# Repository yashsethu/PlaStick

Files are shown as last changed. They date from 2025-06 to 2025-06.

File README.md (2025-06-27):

# PlaStick
An affordable, customizable, and functional HOTAS flight controller!



CAD (here)[https://cad.onshape.com/documents/f1ad626c83caf2a9154e1274/w/2f9358a07325e282af4b0bc9/e/6182394e759cc8585870c80a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]

## Wiring Diagram



These wires are soldered, not part of any PCB

## Bill of Materials
| Quantity | Item | Link |
|---|---|---|
| 2 | Trigger spring 12mm long, 5mm OD, 4mm ID | Find in a ballpoint pen! |
| 2 | 5mmx10mm cylindrical magnet | [Amazon](https://www.amazon.com/Niuknow-Neodymium-10x5x2mm-Double-Sided-Adhesive/dp/B0BTSWZSVG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) |
| 4 | 6802zz Bearings | [Amazon](https://www.amazon.com/INFINAUTO-Bearings-15x24x5mm-Lubricated-Stylish/dp/B0DYNVTPV3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) |
| 4 | 685zz Bearings | [Amazon](https://www.amazon.com/uxcell-Bearing-Double-Shielded-Bearings/dp/B07FW26QBV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) |
| 8 | MF105zz Bearings | [Amazon](https://www.amazon.com/METERXITY-Shielded-Bearings-Wheelbarrow-Machines/dp/B0F4QWG4YM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) |
| 2 | M5x2mm | N/A |
| 2 | M5x30mm | N/A |
| 4 | M5x35mm | N/A |
| 8 | M2x12mm | N/A |
| 4 | M3x10mm | N/A |
| 2 | M3x22mm | N/A |
| 25 | 4.3x6x6 mm tactile switches | [Amazon](https://www.amazon.com/DAOKI-6x6x4-3mm-664-3mm-Momentary-Tactile/dp/B07X8S99RH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) |
| 1 | Arduino Pro Micro | [Amazon](https://www.sparkfun.com/pro-micro-5v-16mhz.html) |
| 3 (these break easily, buy extra) | Hall effect sensor | [Amazon](https://www.amazon.com/AH3503-UGN3503UA-UGN3503-Hall-Effect-Sensors/dp/B09N9SQK79) |

**For the bolts and hardware above, I have ommited links- find them at a hardware store or order a kit off Amazon! Buying them individually is pointless.**
**As for the Arduino Pro Micro, I am buying one direct from Sparkfun to avoid being ripped off with a non-genuine part. It costs 5-10 dollars more, but the complaints online about fake Pro Micros scare me enough into playing it safe** 

**Total Price: 85.99 (this could be a little bit higher or lower depending on Prime/where you live)**

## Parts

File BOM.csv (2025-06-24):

Quantity | Item
2 | M5x25
2 | M5x30
4 | M5x35
4 | 6802zz
8 | MF105zz
4 | 685zz
2 | 5mmx10mm cylindrical magnet
4 | 5-10 mm M3 bolts
2 | 20-22 mm M3 bolts
8 | M2 x 10-12mm
2 | M2 x 10-12mm
1 | Trigger spring 12mm long | 5mm OD | 4mm ID
22-25 | 4.3x6x6 mm tact switches

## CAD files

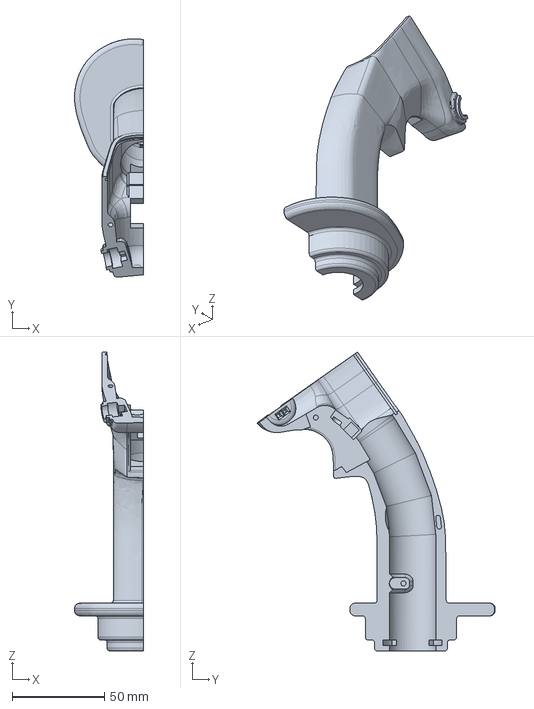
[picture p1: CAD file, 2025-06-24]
CAD/Full Assembly - Part 4.step
37.4 x 129.1 x 162.0 mm

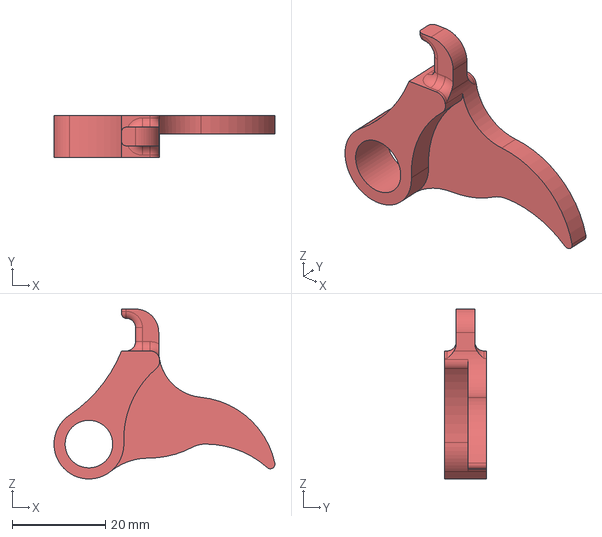
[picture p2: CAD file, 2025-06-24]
CAD/Full Assembly - Part 1 (12).step
47.5 x 9.00 x 36.5 mm

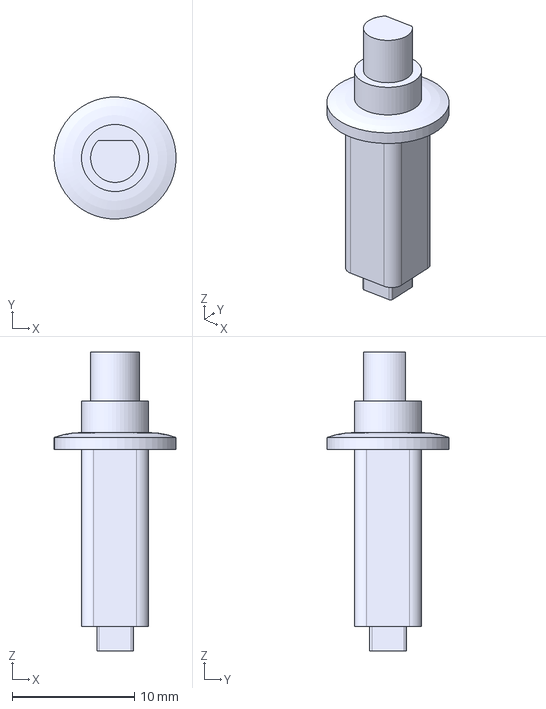
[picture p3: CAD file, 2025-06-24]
CAD/Full Assembly - Part 1 (17).step
9.99 x 10.00 x 24.5 mm

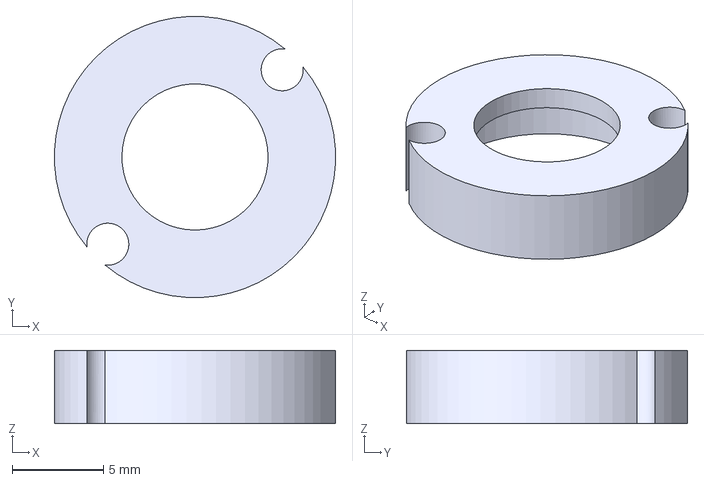
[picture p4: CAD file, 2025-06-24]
CAD/Full Assembly - Part 1 (29).step
15.4 x 15.4 x 4.00 mm

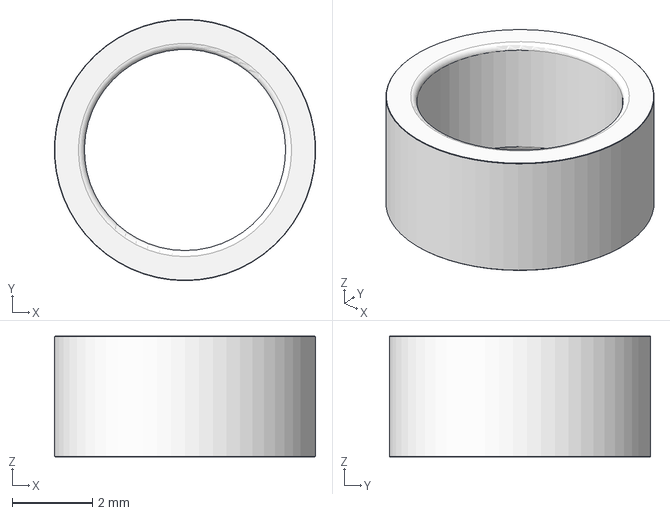
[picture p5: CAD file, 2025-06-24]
CAD/Full Assembly - p BEARING, METRIC 600 MINIATURE SERIES, DOUBLE-SHIELDED 5mm ID × 11 OD × 3 W — 685-ZZ (10).step
6.49 x 6.50 x 3.00 mm

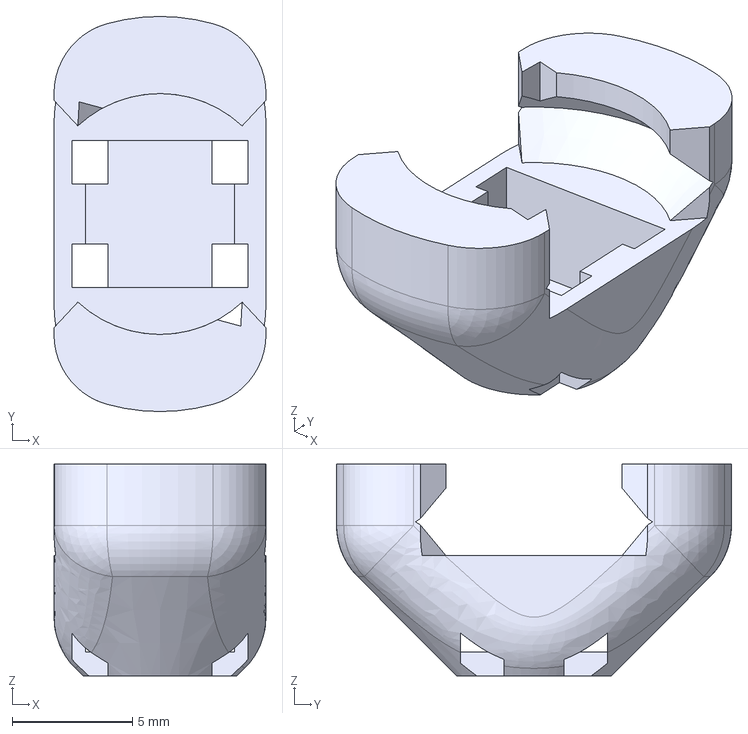
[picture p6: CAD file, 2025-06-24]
CAD/Full Assembly - Part 1 (13).step
8.80 x 16.4 x 8.80 mm

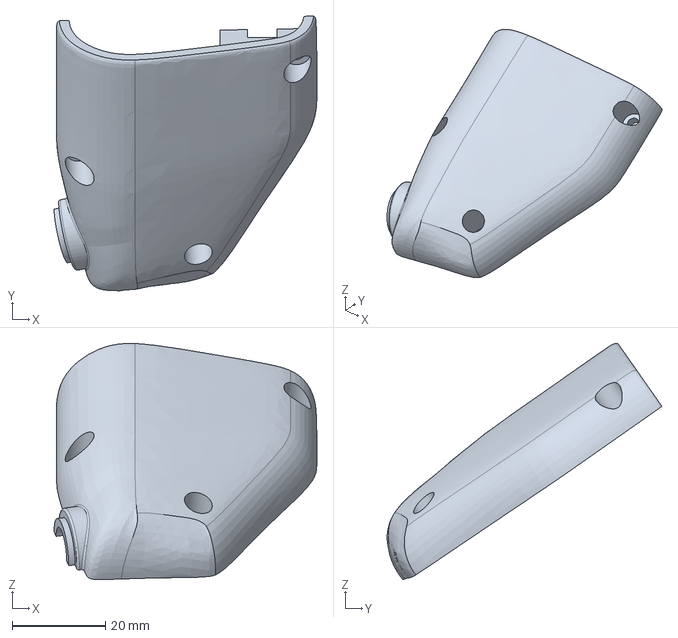
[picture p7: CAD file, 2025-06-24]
CAD/Full Assembly - Part 2.step
56.4 x 58.9 x 50.6 mm

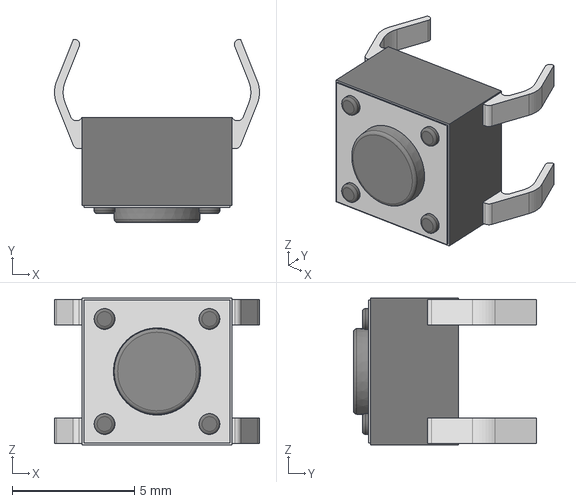
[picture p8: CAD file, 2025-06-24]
CAD/Full Assembly - Part 1 (37).step
8.37 x 7.48 x 5.99 mm

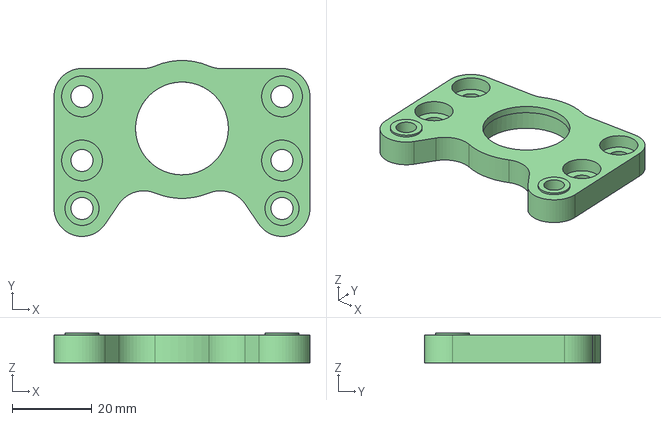
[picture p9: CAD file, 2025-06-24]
CAD/Full Assembly - gimbal_core_bearing_carrier_6802zz.step
64.0 x 44.0 x 7.50 mm

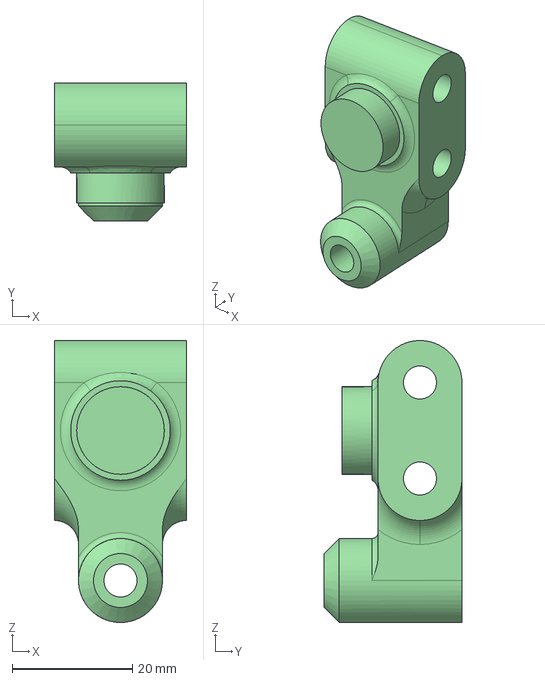
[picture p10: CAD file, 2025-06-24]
CAD/Full Assembly - Part 1 (45).step
22.0 x 23.0 x 47.0 mm

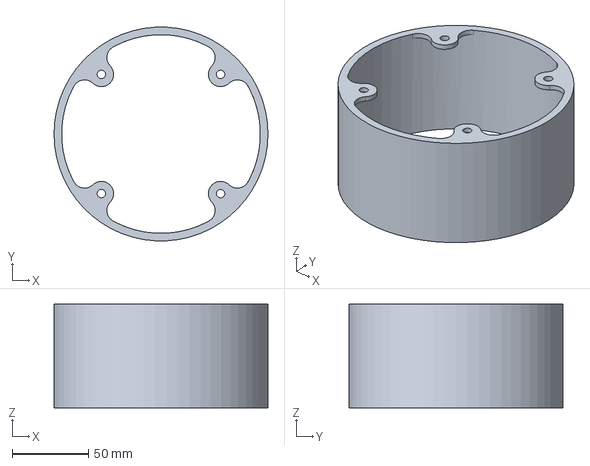
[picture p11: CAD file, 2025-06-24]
CAD/Full Assembly - Part 1 (11).step
140.0 x 139.8 x 68.0 mm

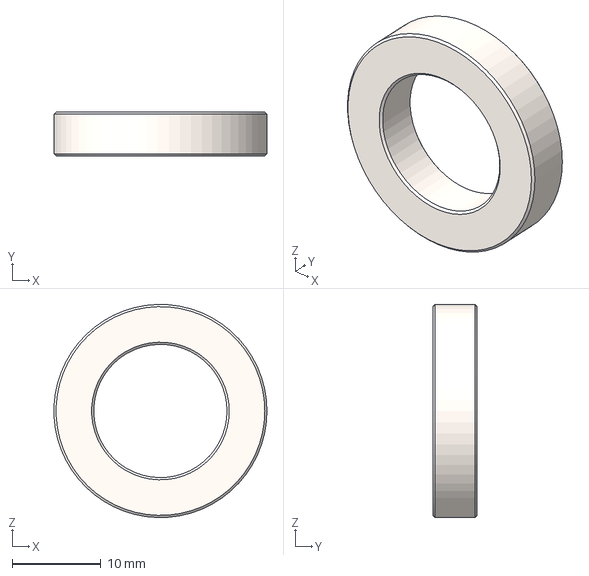
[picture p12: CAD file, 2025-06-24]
CAD/Full Assembly - Part 1 (38).step
24.0 x 5.00 x 24.0 mm

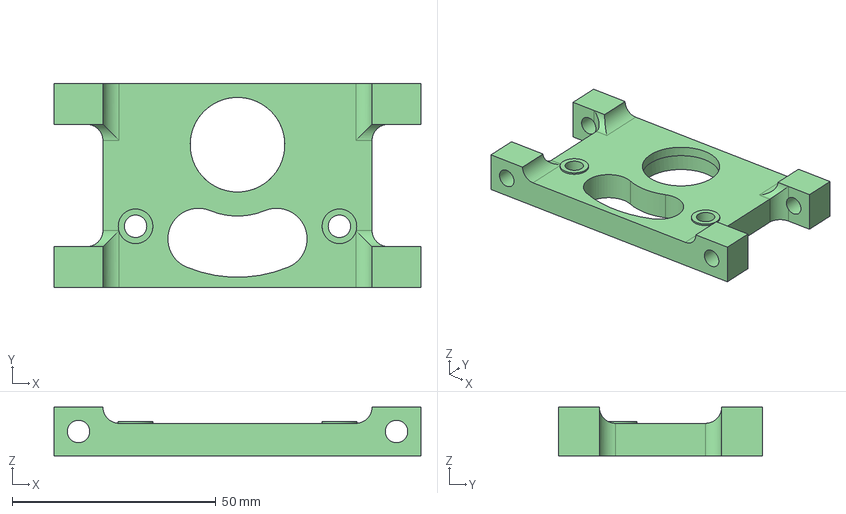
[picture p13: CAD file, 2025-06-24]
CAD/Full Assembly - gimbal_frame_6802zz.step
90.0 x 50.0 x 12.0 mm

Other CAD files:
CAD/Full Assembly - Part 1 (14).step
CAD/Full Assembly - Part 1 (21).step
CAD/Full Assembly - Part 1 (41).step
CAD/Full Assembly - Part 1 (35).step
CAD/Full Assembly - Part 1 (33).step
CAD/Full Assembly - Hex nut grade A & B M5x0.8 (1).step
CAD/Full Assembly - Hex nut grade A & B M5x0.8 (2).step
CAD/Full Assembly - Hex nut grade A & B M5x0.8 (3).step
CAD/Full Assembly - Hex nut grade A & B M5x0.8.step
CAD/Full Assembly - Hex socket countersunk head screw M5x0.8 x 20 (1).step
CAD/Full Assembly - Hex socket countersunk head screw M5x0.8 x 20.step
CAD/Full Assembly - Hex thin nut grade A & B M3 (1).step
CAD/Full Assembly - Hex thin nut grade A & B M3 (2).step
CAD/Full Assembly - Hex thin nut grade A & B M3 (3).step
CAD/Full Assembly - Hex thin nut grade A & B M3.step
CAD/Full Assembly - Hex thin nut grade A & B M5 (1).step
CAD/Full Assembly - Hex thin nut grade A & B M5 (2).step
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

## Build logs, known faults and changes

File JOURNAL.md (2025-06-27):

# Design Journal - Total time: 25 hrs

---
title: "PlaStick"
author: "Yash Sethuraman"
description: "An affordable, customizable HOTAS controller!"
created_at: "2025-06-24"
---

So, I really want a HOTAS flight stick, something like this:



But commercial HOTAS kits and stuff already online is either too expensive or too complicated for me. I want something minimal (at least mechanically) and functional.

# Part 1: The gimbal (3 hrs) 6/20/25

Before going crazy on the actual stick, I thought it would be nice to get the gimal out of the way. The first choice for most DIYers out there (according to Reddit) is a gimbal designed by (Oluleko)[https://www.thingiverse.com/thing:2496028/comments].

I really liked how compact and simple the gimbal was, but looking at the thingiverse, there are STEP files missing from the assembly and no assembly readily available to use. Plus, the project came out nearly 8 years ago. So, I started with making my own Oluleko assembly. 

I started first with redesigning all the parts that were missing from the open source files:

  

Then, I had to find parts. I did some digging to figure out the bearings that Oluleko had used in his design (Thank you Reddit), and scrounged up some CAD for it (No, I don't want to make it myself):

 

Now, I could assemble the gimbal. I used some pictures as reference and made up stuff as I went, adding washers where extra space was neccesary:

 

But wait. This isn't satisfying. There's nothing to move, nothing to prove this actually works. Why not actually make it work in CAD, so I don't have to worry later? Welp, that's what I wasted time doing.

Screen Recording 2025-06-22 at 10 00 04 PM

# Part 2: The box (1 hr) 6/21/25

The other problem with Olukelo's design is that, well, it's just a gimbal. To make this a worthwhile design, I have to design an enclosure for the gimbal. 

Quick sketch of the enclosure:



After extruding everything out, I get something like this:



Then, I can add it to my assembly to check. Enclosure done! There's also enough space underneath for the microcontroller!

 

# Part 3: The stick (5 hrs) 6/22/25

I want to make this HOTAS as realistic as possible, but I don't exactly have an F-16 manual or HOTAS controller lying around to use to design one myself. I started with (this)[https://www.thingiverse.com/thing:4544115] old project to get the basic shape, something like this that I can add to:



Now, I can start actually making the working assembly for the stick!

Working trigger (for fun):

Screen Recording 2025-06-23 at 11 43 04 AM

Added all the button mechanisms (this took a good amount of mating and part sourcing):



Final assembly complete!



Now, for the final touch, I used some eyeballing and measurement to add screws into the right places, so it is truly exactly what I will be building



HOTAS stick done!

# Part 4: Integration (2 hrs) 6/23/25

Now, how to connect these two together? I have to keep a few things in mind:
- Ideally, it should be very very hard to rotate the HOTAS
- The connection should be rigid but easy to take apart (bolts, threads)
- There needs to be wire management built in (i.e wires run through the part)th

With a few basic sketches:



I created a lever arm to be able to integrate seamlessly with another piece:



Then, I did the same to create one for the stick, careful with tolerances:





Now, I can complete the full assembly!

Screen Recording 2025-06-24 at 11 54 09 AM

# Part 5: The electronics (3 hrs) 6/23/25

We're calling this a HOTAS system, but essentially, it's just a really fancy and big mouse. Thus, we need a microcontroller that can become a mouse. One of the easiest ones is the Arduino Pro Micro, so that's what I'll be going with!

Really, this wiring diagram isn't super neccesary, because I will essentially be connecting 20-30 buttons and two hall-effect sensors, which doesn't really require much interfacing, but it's good to be planned out!



With this, I think we can call this done!
